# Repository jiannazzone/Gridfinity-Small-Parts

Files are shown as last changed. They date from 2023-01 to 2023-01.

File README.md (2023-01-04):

# Gridfinity Small Parts Organizer

Organize your small parts in a modular and customizable version of the [small parts](https://www.google.com/search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) cases that are readily available at any hardware store. Why make it yourself when you could buy it for a fair price? Do you even understand 3D printing?! We do it because we can.

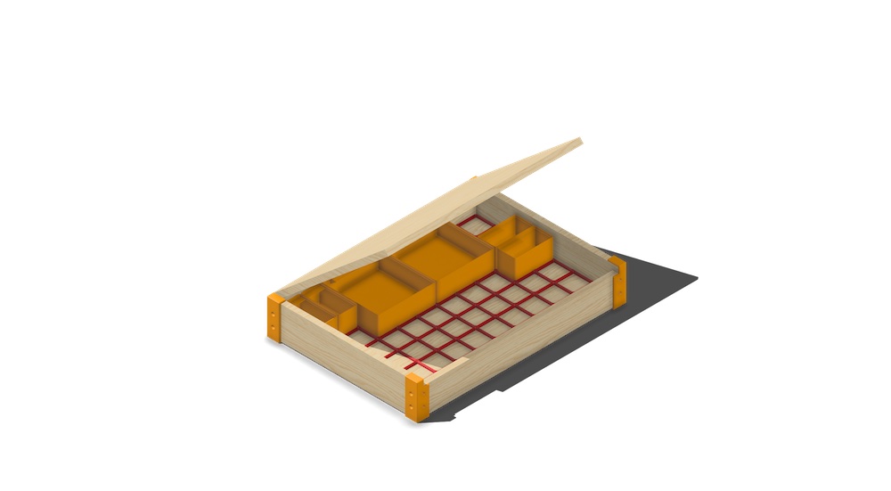
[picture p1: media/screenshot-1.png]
3D render of the Gridfinity box


## Inspiration
This project combines several existing works:
- Alexandre Chappel's [Assortment Boxes](https://youtu.be/VntGnLuwoeY)
- Zack Freedman's [Gridfinity system](https://www.youtube.com/watch?v=ra_9zU-mnl8)
- Kennetek's OpenSCAD [Gridfinity Rebuilt](https://github.com/kennetek/gridfinity-rebuilt-openscad) project.

If you want to keep things simple, Chappel has a great set of [plans and STLs](https://www.alch.shop/shop/assortment) for his Assortment system. This is a great solution if you don't want too much customization. However, the Gridfinity platform has **HUGE** community support with a large number of mods, derivatives, and compatible parts. I wanted to use the Chappel box idea, but with the Gridfinity system inside.

## The Parts
- [Corner Bumpers](STLs)
- [Cut list](Cut%20List.pdf) – Plywood is 1/2" or 12mm.
- [Hinge Files by Josef Průša](https://www.printables.com/model/202-hinge) – I used the small hinge
- [Handle by Bwolfey](https://www.printables.com/model/1054-toolbox-handle)
- Since the latches are part of [Chappel's paid plans](https://www.alch.shop/shop/p/assortment-case), I will not include STLs here. You are welcome to purchase his (for a very reasonable price) or come up with your own.

## The Details
-  This is a `7x10x6u` grid.
    - I picked the size by looking at other small parts boxes and trying to come up with a similar dimension.
    - This allows for a lot of layout flexibility and allows the bins to hold plenty of screws without getting too bulky.
    - If you want to adjust the base dimensions, just add or remove `42mm` in any direction of the cut list.
- The short edges are proud (up to the level of the lid) to prevent small parts from slipping through a gap between the lid and the sides.
- The lid rests on top of the long edges (where it attaches with hings and latches)
- With the lid closed, you can shake the box any way you like! Nothing should fall out of place.
- All joints are simple butt joints, and the sides sit on top of the bottom panel.

## Images for Assembly Reference
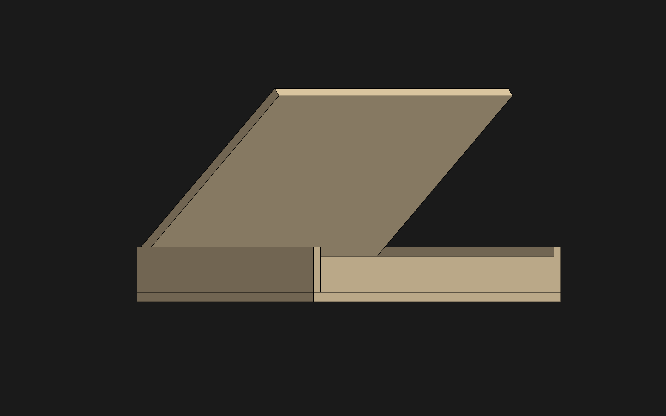
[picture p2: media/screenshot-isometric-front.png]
Front isometric view

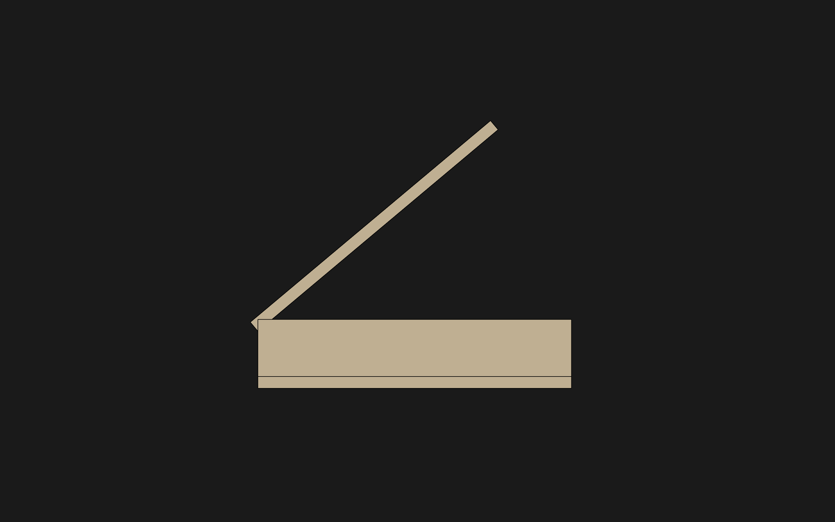
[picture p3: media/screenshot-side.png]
Side View

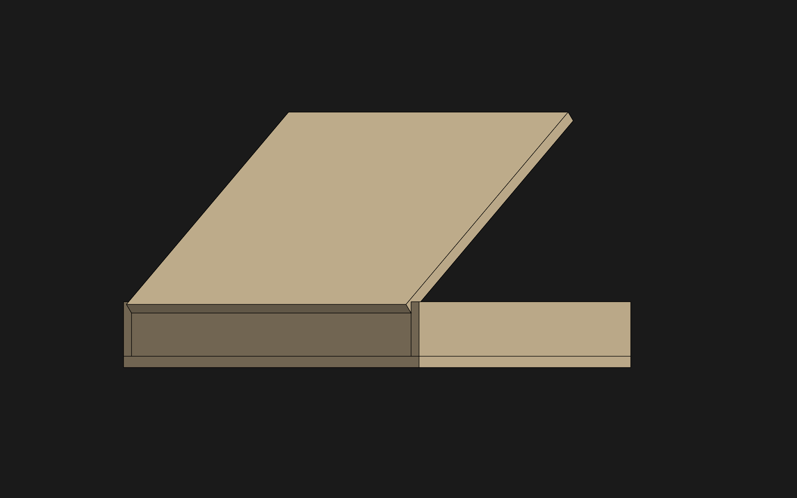
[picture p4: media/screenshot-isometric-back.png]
Rear isometric view


## Completed Box
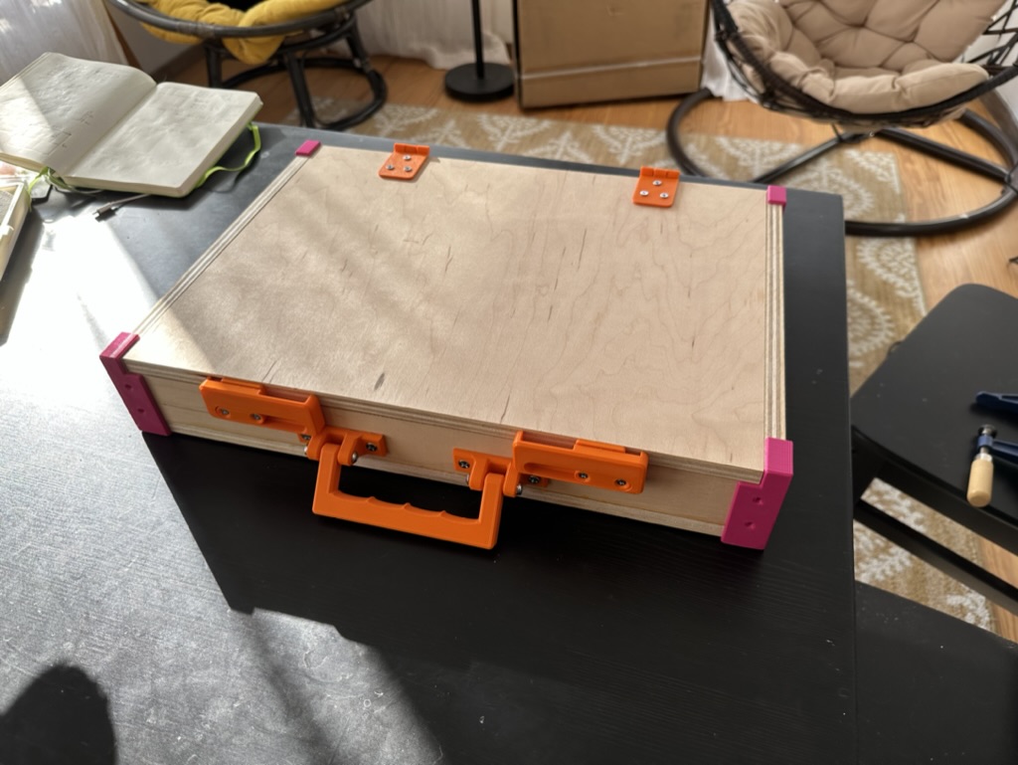
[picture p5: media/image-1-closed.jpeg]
Completed box, closed.

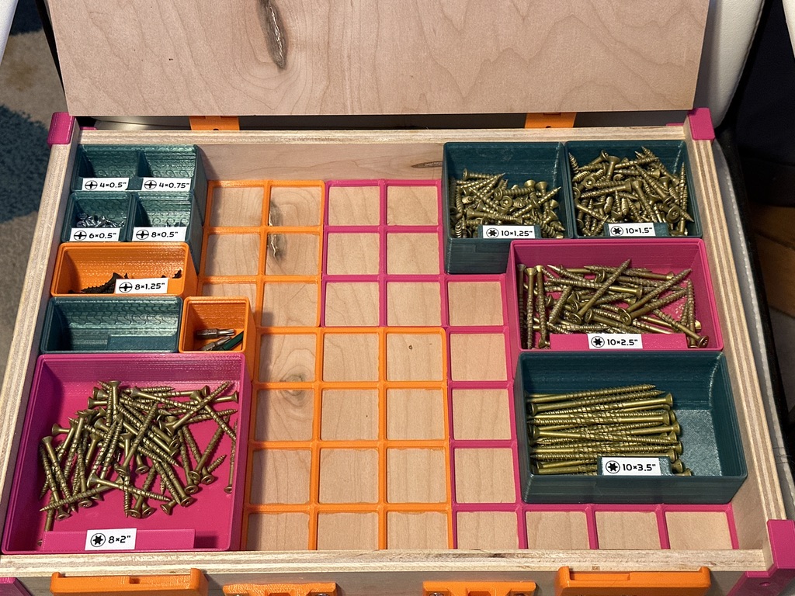
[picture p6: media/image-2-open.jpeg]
Completed box, open.


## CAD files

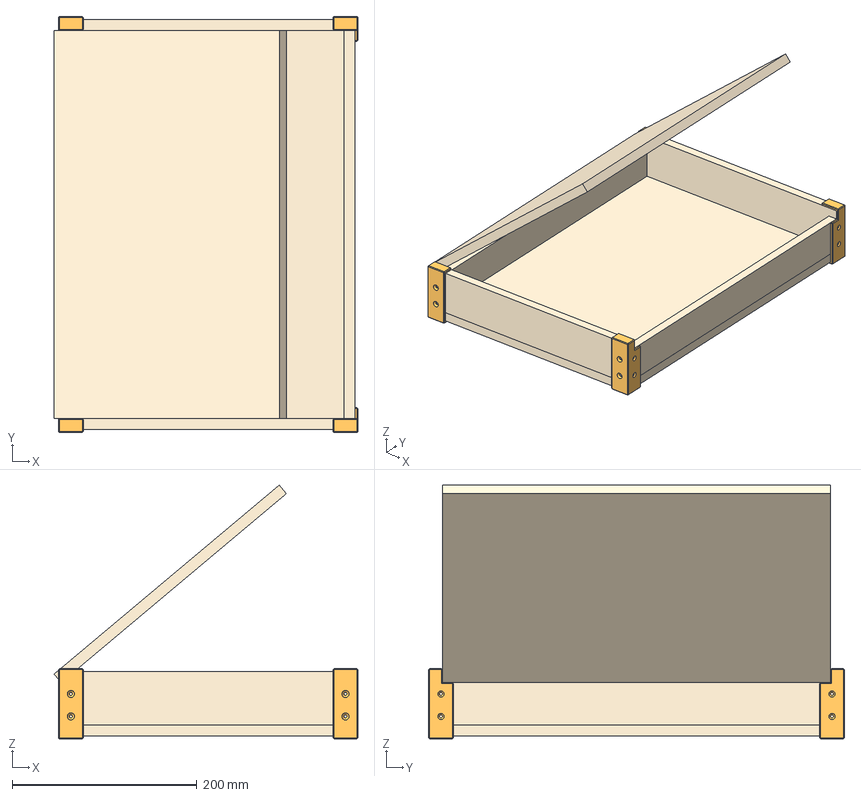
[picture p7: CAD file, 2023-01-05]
source-files/12mm/Gridfinity Box.step
328.7 x 450.0 x 274.5 mm
Corner Bumpers

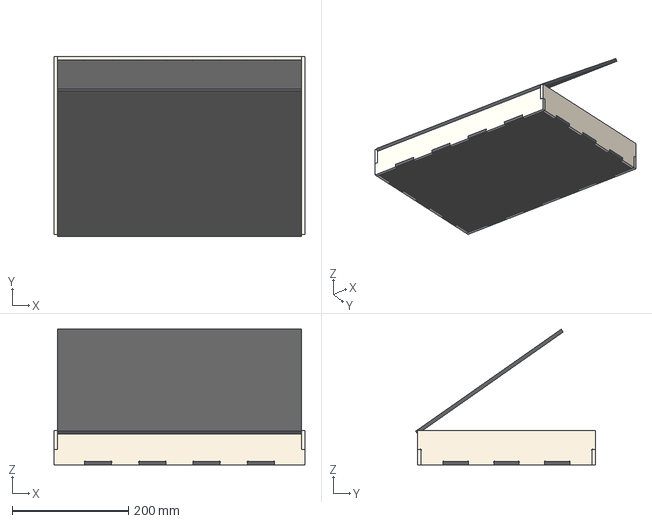
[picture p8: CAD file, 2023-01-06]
source-files/6mm/parametric_grifinity_box_6mm.step
432.0 x 309.4 x 233.4 mm

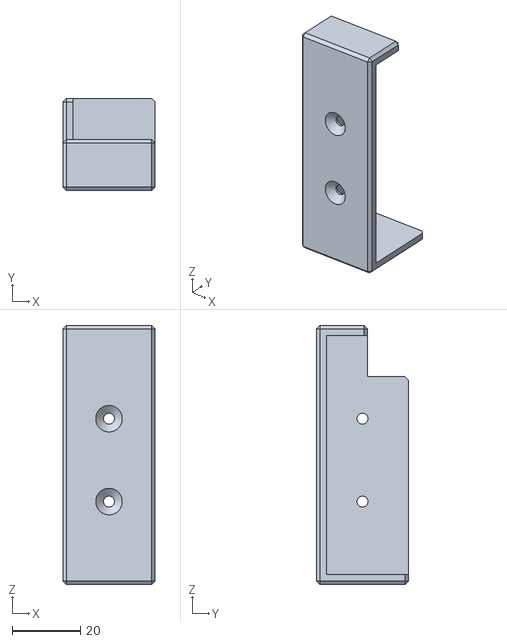
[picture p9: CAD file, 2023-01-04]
source-files/12mm/BL Bumper.stl
27.0 x 27.0 x 75.9

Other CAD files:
source-files/12mm/BR Bumper.stl
source-files/12mm/FR Bumper.stl
source-files/12mm/FL Bumper.stl
source-files/12mm/Gridfinity Box.f3d
source-files/6mm/parametric_grifinity_box_6mm.f3d

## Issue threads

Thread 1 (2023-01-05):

Source files

MichaelMartinez, 2023-01-05:
Thank you for posting the files for your box. Are you going to release the source files? I would help create different sized thicknesses for the wood panels. I can also create some finger joints for CNC manufacture. Further ideas include a 3d printed locking/stacking mechanism similar to packout and other modular toolboxes.

Closed 2023-01-05.

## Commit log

2023-01-04 - Add STLS - Update README
    [BL Bumper.stl, BR Bumper.stl, FL Bumper.stl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]
2023-01-04 Add assembly reference images
2023-01-05 Add source files
    Added STEP and F3D files
    [Gridfinity Box.f3d, Gridfinity Box.step]
2023-01-06 added 6mm cnc ready files
    [parametric_grifinity_box_6mm.f3d, parametric_grifinity_box_6mm.step]
2023-01-06 Reorganized files
    Moved files into folders based on material thickness in anticipation of 6mm version
    [BL Bumper.stl, BR Bumper.stl, FL Bumper.stl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]
